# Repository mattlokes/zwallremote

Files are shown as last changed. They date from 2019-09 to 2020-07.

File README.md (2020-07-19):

# zwallremote
zwallremote (Zigbee Wall Remote) is a device based on TI's CC2530 Zigbee Tranciever with built in 8051. Which allows you to reuse your existing light switches to control Tradfi, Hue or other Zigbee Light Link lights.

In fact it actaully acts as a small cheap zigbee remote for all sorts of diffrent uses. For my use case i use it to send commands to zigbee2mqtt which are passed onto HomeAssistant for controlling my Tradfri light network. However there is no reason you could not use it to turn your TV on play music on some smart speakers.

# Basics
After booting, the zwallremote polls once a second to detect the state of the screw terminal. If there is a change in state it will send a ZCL_TOGGLE_CMD to the co-ordinator, currently a fixed address in the firmware. I measured current use to be approximately 2uA so it should be capable of running for over 2 years on a single CR2032 coin cell (depending on how many times the light switch is used). 

# PCB

No known issues, worked first time with my cheap aliexpress CC2530 modules. Pretty Simple

# Firmware
You can either:
1. Can use precompiled binary in firmware/bin/
  - Will need to change the address of your co-ordinator (currently 0x0012_4B00_02C5_A0A6)
    - Line 2053 of the hex file, its reverse byte ordered, see https://imgur.com/1fYdB8f.
  - TODO give script for manipulate the hex file
  
2. Comple it yourself:
  - Will need IAR workbench 8051.
  - TI's Z-Stack Home 1.2.2a.44539.
  - The files are just modification to the SampleSwitch example application so just replace files as required.
  - Patience, Prayer and Screaming.
  
# Zigbee2mqtt changes (Now on mainline zigbee2mqtt)

1. You need to add ZWallRemote to "const devices" list of dictionaries in "node_modules/zigbee-shepherd-converters/devices.js":

```python
const devices = [
...
  {
      zigbeeModel: ['ZWallRemote0'],
      model: 'ZWallRemote0',
      vendor: 'Custom devices (DiY)',
      description: 'Matts Wall Switch Remote (https://github.com/mattlokes/ZWallRemote)'
      supports: 'on/off',
      fromZigbee: [ fz.cmdToggle ],
      toZigbee: [],
  },
...
]
```

2. Add "ZWallRemote0" to the "const mapping" dictionary in "lib/extension/homeassistant.js"

```python
const mapping = { 
 ...
    'ZWallRemote0': [ configurations.sensor_action ]
 ...
 }
```

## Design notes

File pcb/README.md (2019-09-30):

The KiCad PCB uses a custom footprint i made for the SZ1v5 CC2530 module from aliexpress:

1. Add the follow footprint to "kicad/library/RF_Module.lib"

```
# SZ1v5
#
DEF SZ1v5 U 0 40 Y Y 1 F N
F0 "U" 0 -200 50 H V C CNN
F1 "SZ1v5" 0 150 50 H V C CNN
F2 "RF_Module:SZ1v5" 0 0 50 H V C CNN
F3 "" 0 -200 50 H I C CNN
DRAW
S 750 -650 -750 625 0 1 10 f
X GND 1 750 450 100 R 50 50 0 0 W
X P1_4 10 750 -450 100 R 50 50 0 0 B
X P1_3 11 750 -550 100 R 50 50 0 0 B
X P0_1 14 -750 350 100 L 50 50 0 0 B
X P0_2 15 -750 250 100 L 50 50 0 0 B
X P0_3 16 -750 150 100 L 50 50 0 0 B
X P0_4 17 -750 50 100 L 50 50 0 0 B
X P0_5 18 -750 -50 100 L 50 50 0 0 B
X P0_6 19 -750 -150 100 L 50 50 0 0 B
X 3V3 2 750 350 100 R 50 50 0 0 W
X P0_7 20 -750 -250 100 L 50 50 0 0 B
X P1_0 21 -750 -350 100 L 50 50 0 0 B
X P1_1 22 -750 -450 100 L 50 50 0 0 B
X P1_2 23 -750 -550 100 L 50 50 0 0 B
X 3V3 3 750 250 100 R 50 50 0 0 W
X P2_2 4 750 150 100 R 50 50 0 0 B
X P2_1 5 750 50 100 R 50 50 0 0 B
X P2_0 6 750 -50 100 R 50 50 0 0 B
X P1_7 7 750 -150 100 R 50 50 0 0 B
X P1_6 8 750 -250 100 R 50 50 0 0 B
X P1_5 9 750 -350 100 R 50 50 0 0 B
X GND 0 750 550 100 R 50 50 1 1 W
X RST_N 12 -750 550 100 L 50 50 1 1 I
X P0_0 13 -750 450 100 L 50 50 1 1 B
ENDDRAW
ENDDEF
```
2. Add the footprint description to "kicad/library/RF_Module.dcm"

```
$CMP SZ1v5
D cc2530 Zigbee Module
$ENDCMP
```

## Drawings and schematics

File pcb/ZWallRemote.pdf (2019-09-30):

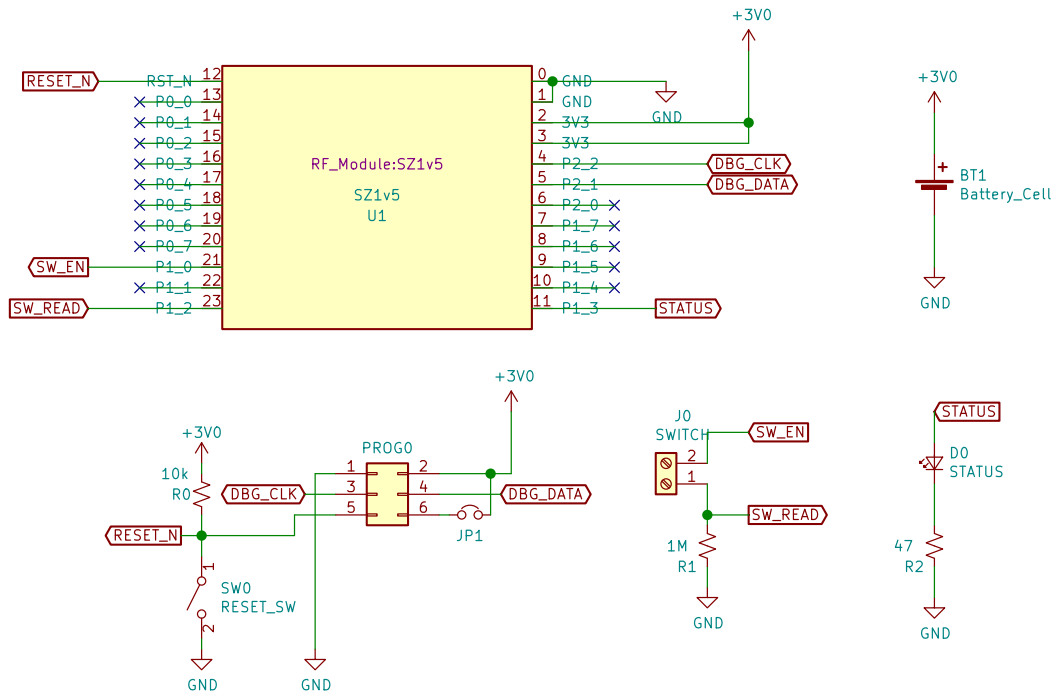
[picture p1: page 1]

Id: 1/1 Title: File: ZWallRemote.sch Sheet: /

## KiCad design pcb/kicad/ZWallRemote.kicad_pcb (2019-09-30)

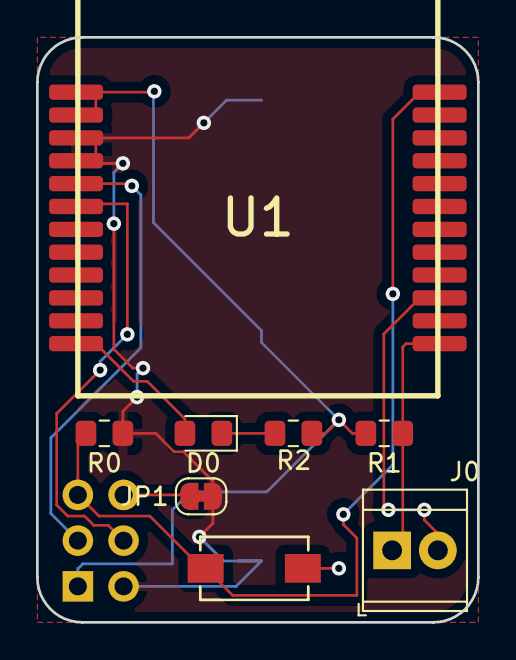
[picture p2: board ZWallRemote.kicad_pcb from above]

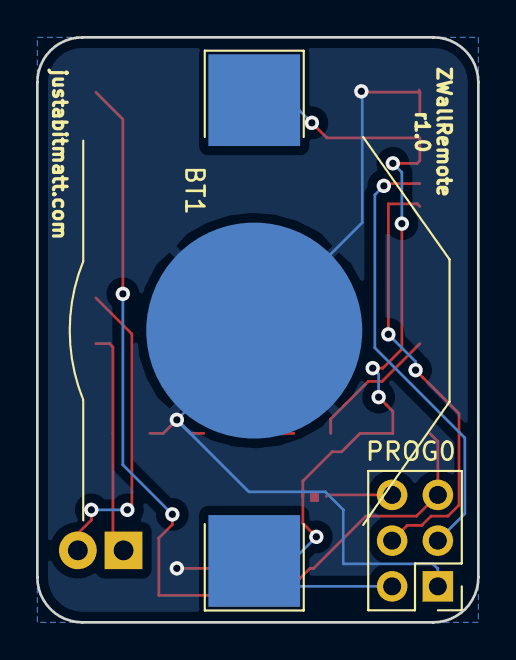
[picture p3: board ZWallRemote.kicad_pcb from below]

Board: 2 copper layers, 24.5 x 32.5 mm, 10 parts (2 on the bottom side), 10 nets.

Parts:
BT1: Battery_Cell; BatteryHolder_Keystone_3002_1x2032
D0: STATUS; LED_0805_2012Metric_Pad1.15x1.40mm_HandSolder
J0: SWITCH; TerminalBlock_TE_282834-2_1x02_P2.54mm_Horizontal
JP1: Jumper_NO_Small; SolderJumper-2_P1.3mm_Bridged_RoundedPad1.0x1.5mm
PROG0: Conn_02x03_Odd_Even; PinHeader_2x03_P2.54mm_Vertical
R0: 10k; R_0805_2012Metric_Pad1.15x1.40mm_HandSolder
R1: 1M; R_0805_2012Metric_Pad1.15x1.40mm_HandSolder
R2: 47; R_0805_2012Metric_Pad1.15x1.40mm_HandSolder
SW0: RESET_SW; DTSM-32S-B
U1: SZ1v5

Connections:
+3V0: BT1.1, JP1.2, PROG0.2, R0.1, U1.2, U1.3
DBG_CLK: PROG0.3, U1.4
DBG_DATA: PROG0.4, U1.5
GND: BT1.2, PROG0.1, R1.2, R2.2, SW0.2, U1.0, U1.1
unnamed: D0.1, R2.1
unnamed: JP1.1, PROG0.6
RESET_N: PROG0.5, R0.2, SW0.1, U1.12
STATUS: D0.2, U1.11
SW_EN: J0.2, U1.21
SW_READ: J0.1, R1.1, U1.23

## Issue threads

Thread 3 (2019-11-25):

Multi action.

arcidodo, 2019-11-25:
Hi,

Is it possible to create multiple functions like:

1 press = toggle
1 press & hold = dimm down, until release
2 time press & hold = dimm up, until release

I use an wall switch with an spring.

This would be awesome! I have now an esp in the wall to do this but if home assistant is down it is not working.

It is basically the same function of the ikea tradfri on/off switch but than with one button.

mattlokes, 2019-11-25:
Hi,

There’s no technical reason why not, but it would require further
development. If you get an IAR evaluation license you can extend this
yourself :)

Thanks
Matt

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

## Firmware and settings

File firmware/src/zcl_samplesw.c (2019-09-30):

/**************************************************************************************************
  Filename:       zcl_samplesw.c
  Revised:        $Date: 2015-08-19 17:11:00 -0700 (Wed, 19 Aug 2015) $
  Revision:       $Revision: 44460 $

  Description:    Zigbee Cluster Library - sample device application.


  Copyright 2006-2013 Texas Instruments Incorporated. All rights reserved.

  IMPORTANT: Your use of this Software is limited to those specific rights
  granted under the terms of a software license agreement between the user
  who downloaded the software, his/her employer (which must be your employer)
  and Texas Instruments Incorporated (the "License").  You may not use this
  Software unless you agree to abide by the terms of the License. The License
  limits your use, and you acknowledge, that the Software may not be modified,
  copied or distributed unless embedded on a Texas Instruments microcontroller
  or used solely and exclusively in conjunction with a Texas Instruments radio
  frequency transceiver, which is integrated into your product.  Other than for
  the foregoing purpose, you may not use, reproduce, copy, prepare derivative
  works of, modify, distribute, perform, display or sell this Software and/or
  its documentation for any purpose.

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
  Should you have any questions regarding your right to use this Software,
  contact Texas Instruments Incorporated at www.TI.com.
**************************************************************************************************/

/*********************************************************************
  This device will be like an On/Off Switch device. This application
  is not intended to be a On/Off Switch device, but will use the device
  description to implement this sample code.

  ----------------------------------------
  Main:
    - SW1: Toggle remote light
    - SW2: Invoke EZMode
    - SW4: Enable/Disable Permit Join
    - SW5: Go to Help screen
  ----------------------------------------
*********************************************************************/

/*********************************************************************
 * INCLUDES
 */
#include "ZComDef.h"
#include "OSAL.h"
#include "AF.h"
#include "ZDApp.h"
#include "ZDObject.h"
#include "ZDProfile.h"
#include "MT_SYS.h"
#include <string.h>

#include "zcl.h"
#include "zcl_general.h"
#include "zcl_ha.h"
#include "zcl_samplesw.h"
#include "zcl_ezmode.h"

#include "onboard.h"

/* HAL */
#include "hal_lcd.h"
#include "hal_led.h"
#include "hal_key.h"

#if defined (OTA_CLIENT) && (OTA_CLIENT == TRUE)
#include "zcl_ota.h"
#include "hal_ota.h"
#endif


/*********************************************************************
 * MACROS
 */

/*********************************************************************
 * CONSTANTS
 */
/*********************************************************************
 * TYPEDEFS
 */

/*********************************************************************
 * GLOBAL VARIABLES
 */
byte zclSampleSw_TaskID;

byte zclSampleSw_CurrentStateValid = 0;
byte zclSampleSw_CurrentState = 0;
const uint8 zclSampleSw_CoordAddrDefault[] = { 0xA6, 0xA0, 0xC5, 0x02, 0x00, 0x4B, 0x12, 0x00};
afAddrType_t coordDstAddr;

uint8 zclSampleSwSeqNum;

uint8 zclSampleSw_OnOffSwitchType = ON_OFF_SWITCH_TYPE_TOGGLE;

uint8 zclSampleSw_OnOffSwitchActions = ON_OFF_SWITCH_ACTIONS_2;   // Toggle -> Toggle

/*********************************************************************
 * GLOBAL FUNCTIONS
 */

/*********************************************************************
 * LOCAL VARIABLES
 */
#ifdef ZCL_ON_OFF
afAddrType_t zclSampleSw_DstAddr;
#endif

#ifdef ZCL_EZMODE
static void zclSampleSw_ProcessZDOMsgs( zdoIncomingMsg_t *pMsg );
static void zclSampleSw_EZModeCB( zlcEZMode_State_t state, zclEZMode_CBData_t *pData );

static const zclEZMode_RegisterData_t zclSampleSw_RegisterEZModeData =
{
  &zclSampleSw_TaskID,
  SAMPLESW_EZMODE_NEXTSTATE_EVT,
  SAMPLESW_EZMODE_TIMEOUT_EVT,
  &zclSampleSwSeqNum,
  zclSampleSw_EZModeCB
};

// NOT ZLC_EZMODE, Use EndDeviceBind
#else

static cId_t bindingOutClusters[] =
{
  ZCL_CLUSTER_ID_GEN_ON_OFF
};
#define ZCLSAMPLESW_BINDINGLIST   (sizeof(bindingOutClusters)/sizeof(bindingOutClusters[0]))
#endif  // ZLC_EZMODE

// Endpoint to allow SYS_APP_MSGs
static endPointDesc_t sampleSw_TestEp =
{
  SAMPLESW_ENDPOINT,                  // endpoint
  &zclSampleSw_TaskID,
  (SimpleDescriptionFormat_t *)NULL,  // No Simple description for this test endpoint
  (afNetworkLatencyReq_t)0            // No Network Latency req
};

uint8 giSwScreenMode = SW_MAINMODE;   // display the main screen mode first

static uint8 aProcessCmd[] = { 1, 0, 0, 0 }; // used for reset command, { length + cmd0 + cmd1 + data }

uint8 gPermitDuration = 0;    // permit joining default to disabled

devStates_t zclSampleSw_NwkState = DEV_INIT;

#if defined (OTA_CLIENT) && (OTA_CLIENT == TRUE)
#define DEVICE_POLL_RATE                 8000   // Poll rate for end device
#endif

/*********************************************************************
 * LOCAL FUNCTIONS
 */
static void zclSampleSw_SwitchRead( void );
static void zclSampleSw_HandleKeys( byte shift, byte keys );
static void zclSampleSw_BasicResetCB( void );
static void zclSampleSw_IdentifyCB( zclIdentify_t *pCmd );
static void zclSampleSw_IdentifyQueryRspCB(  zclIdentifyQueryRsp_t *pRsp );
static void zclSampleSw_ProcessIdentifyTimeChange( void );

// app display functions
void zclSampleSw_LcdDisplayUpdate(void);
void zclSampleSw_LcdDisplayMainMode(void);
void zclSampleSw_LcdDisplayHelpMode(void);

// Functions to process ZCL Foundation incoming Command/Response messages
static void zclSampleSw_ProcessIncomingMsg( zclIncomingMsg_t *msg );
#ifdef ZCL_READ
static uint8 zclSampleSw_ProcessInReadRspCmd( zclIncomingMsg_t *pInMsg );
#endif
#ifdef ZCL_WRITE
static uint8 zclSampleSw_ProcessInWriteRspCmd( zclIncomingMsg_t *pInMsg );
#endif
static uint8 zclSampleSw_ProcessInDefaultRspCmd( zclIncomingMsg_t *pInMsg );
#ifdef ZCL_DISCOVER
static uint8 zclSampleSw_ProcessInDiscCmdsRspCmd( zclIncomingMsg_t *pInMsg );
static uint8 zclSampleSw_ProcessInDiscAttrsRspCmd( zclIncomingMsg_t *pInMsg );
static uint8 zclSampleSw_ProcessInDiscAttrsExtRspCmd( zclIncomingMsg_t *pInMsg );
#endif

#if defined (OTA_CLIENT) && (OTA_CLIENT == TRUE)
static void zclSampleSw_ProcessOTAMsgs( zclOTA_CallbackMsg_t* pMsg );
#endif
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
